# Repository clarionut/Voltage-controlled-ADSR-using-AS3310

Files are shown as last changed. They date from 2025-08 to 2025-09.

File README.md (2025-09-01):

# Voltage controlled ADSR using AS3310



This repository contains details of my modified version of the [Digisound 80-18 multifunction envelope generator]( http://www.digisound80.co.uk/digisound/modules/80-18.htm). I was particularly interested in its versatility with three operating modes
- normal (standard ADSR)
- automatic (gives a complete ADR cycle following a brief trigger input)
- damped (gives a piano-like envelope with initial attack and decay, but instead of a constant sustain while the gate is high the envelope continues to decay at a rate determined by the release setting, finally shutting off the envelope when the gate goes low)

Curiously, given that the 3310 chip is intrinsically voltage controlled, the Digisound 80-18 module only featured control of the envelope by potentiometers rather than allowing external CV control, although there are other designs (e.g. by [gerb-ster](https://github.com/gerb-ster/Curtis-VC-ADSR)) which do allow external control.

I'm absolutely delighted with this module and immediately built a second. I wouldn't want to be limited to a conventional ADSR having used this one.

## Issues
There is a known issue with the Digisound 80-18 module leading to repeated AD triggering with relatively weak gate inputs. The Digisound 80-18A documentation suggests using two gates from a CD40106 in series to condition the gate signal and [Eddy Bergman used a switch](https://www.eddybergman.com/2020/05/synthesizer-build-part-33-digisound-80.html) to break the loop responsible for multiple triggering. I chose to feed the gate input into an op-amp comparator so even rather low-level gates trigger the ADSR reliably.

Note that I have not encountered any of the odd behaviour in Automatic mode as described by Eddy Bergman, in my case this mode works exactly as described in the Digisound 80-18 documentation.

Running the circuit on a breadboard showed that with linear potentiometers much of the travel of the pot covered only very short time intervals, making the more useful longer times quite hard to adjust. This was easy to fix using fake C-taper pots (500k linear pot with a 100k resistor from the wiper to the +ve supply end of the pot).

## Additional features
I found that in Damped mode the final release was very rapid producing an audible click. Adding a 510R resistor between the AS3310 chip pin 13 and transistor TR2 (Digisound schematic) / Q2 (my schematic) gave a rapid release without clicking. In the end I added a 2k 'Release 2' pot to make this final release phase manually adjustable.

Coincidentally, at the time I was working on this circuit I was also fixing an issue with the envelope generator of the filter in my Formanta Polivoks. This has an autorepeat mode, enabled by setting the envelope to AD mode and the sustain level to zero. It uses an op-amp comparator to generate an internal trigger signal when the envelope voltage falls below a threshold of a few mV. I included this feature in this ADSR, providing an 'end of envelope' output to trigger other events in the synth, and included a LOOP option on the mode switch allowing the module to run continously (essentially as an 'ADR LFO') in Automatic mode with frequencies up to about 120Hz.

The decay CV input is normalled to the attack input and the release input is normalled to decay, allowing flexibility in external CV control.

There are out-of-range monitor LEDs on the four CV inputs to warn if the combined potentiometer & external CV levels exceed the maximum useful control voltage (no damage would result, it simply wouldn't be effective).

## Repository contents
The schematics folder contains the full schematic as a PDF document, the PCB layout (with the front ground plane removed for clarity) and a subfolder containing the kicad 7 project. The kicad schematic and PCB use some custom symbols and footprints so you may have to download my custom [kiCad libraries](https://github.com/clarionut/kiCad_libraries). Note that the PCB layout is intended to be processed by the 'round tracks' kicad plugin as shown in the PCB.pdf document. The kicad project files only include the unprocessed .kicad_pcb file. I've also included the Gerbers (in the Gerbers folder!) of the rounded tracks PCB for direct fabrication in case they're useful for anyone.

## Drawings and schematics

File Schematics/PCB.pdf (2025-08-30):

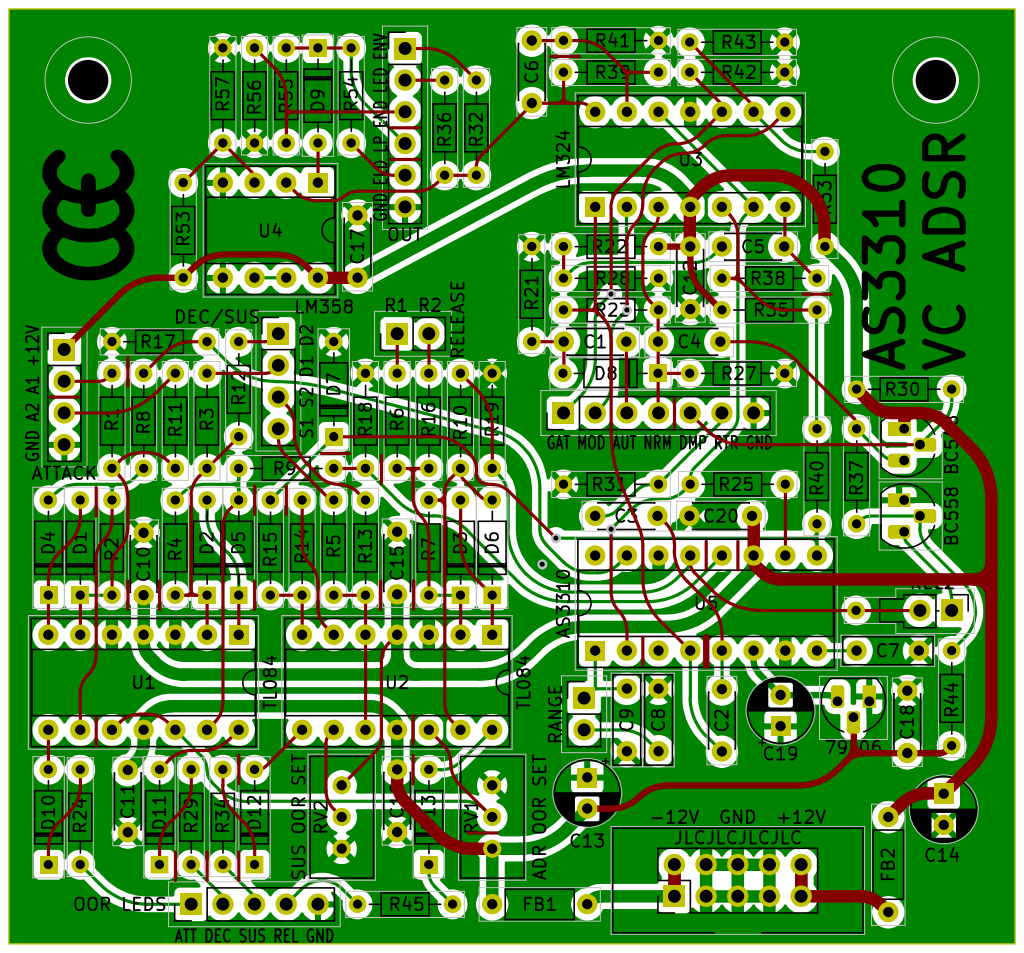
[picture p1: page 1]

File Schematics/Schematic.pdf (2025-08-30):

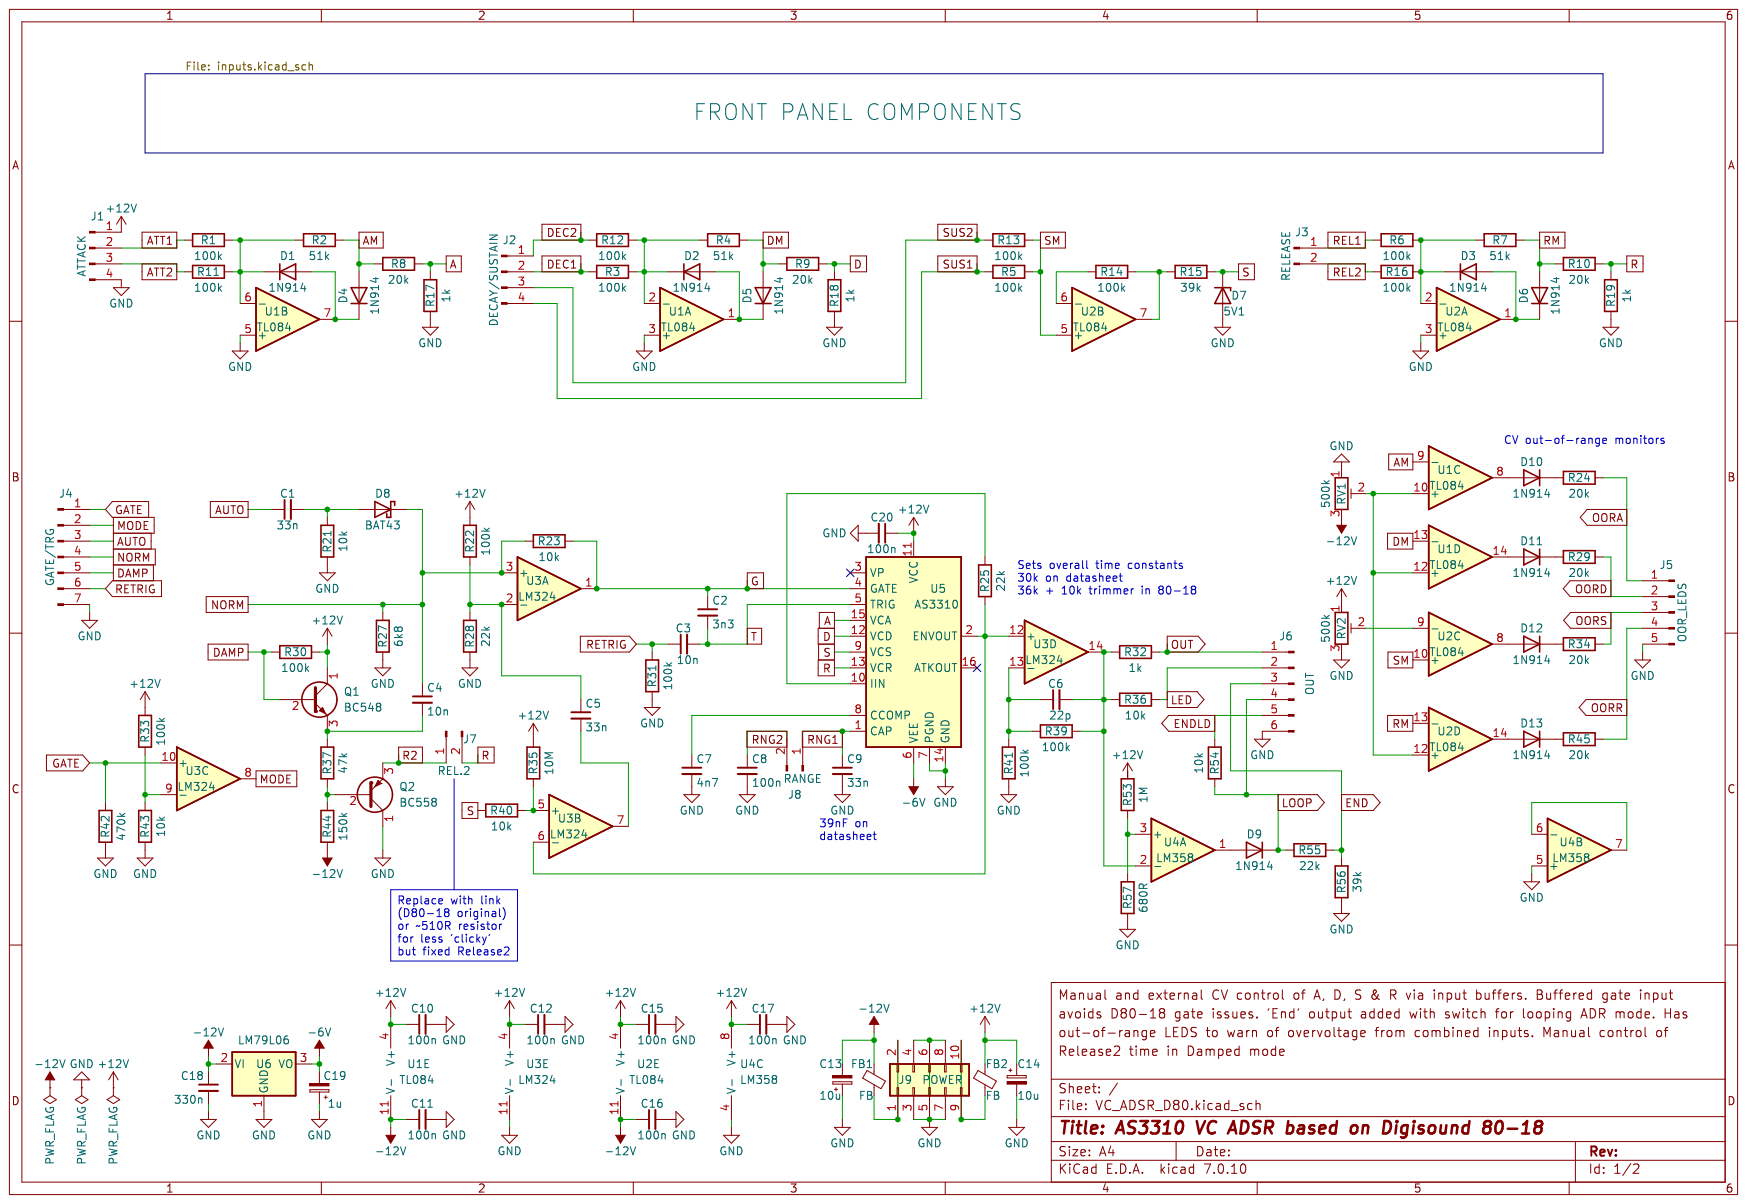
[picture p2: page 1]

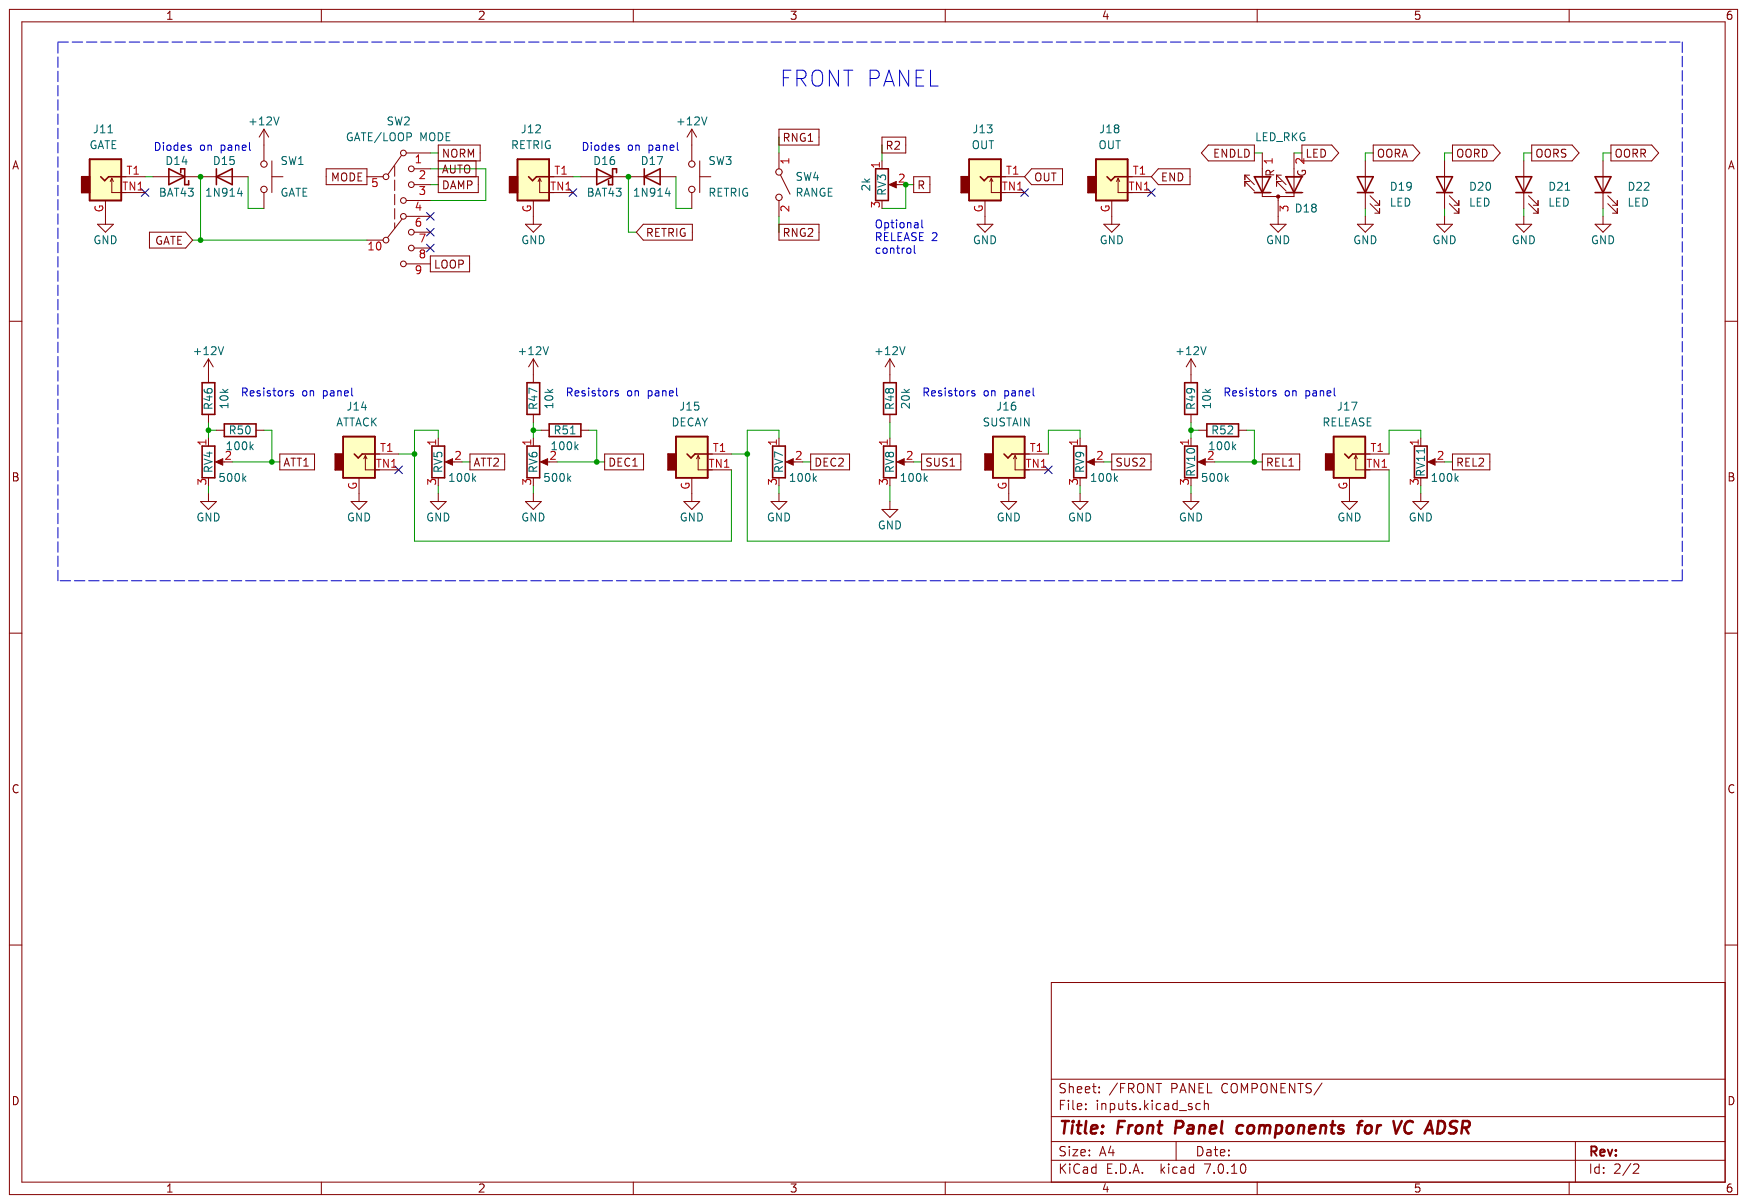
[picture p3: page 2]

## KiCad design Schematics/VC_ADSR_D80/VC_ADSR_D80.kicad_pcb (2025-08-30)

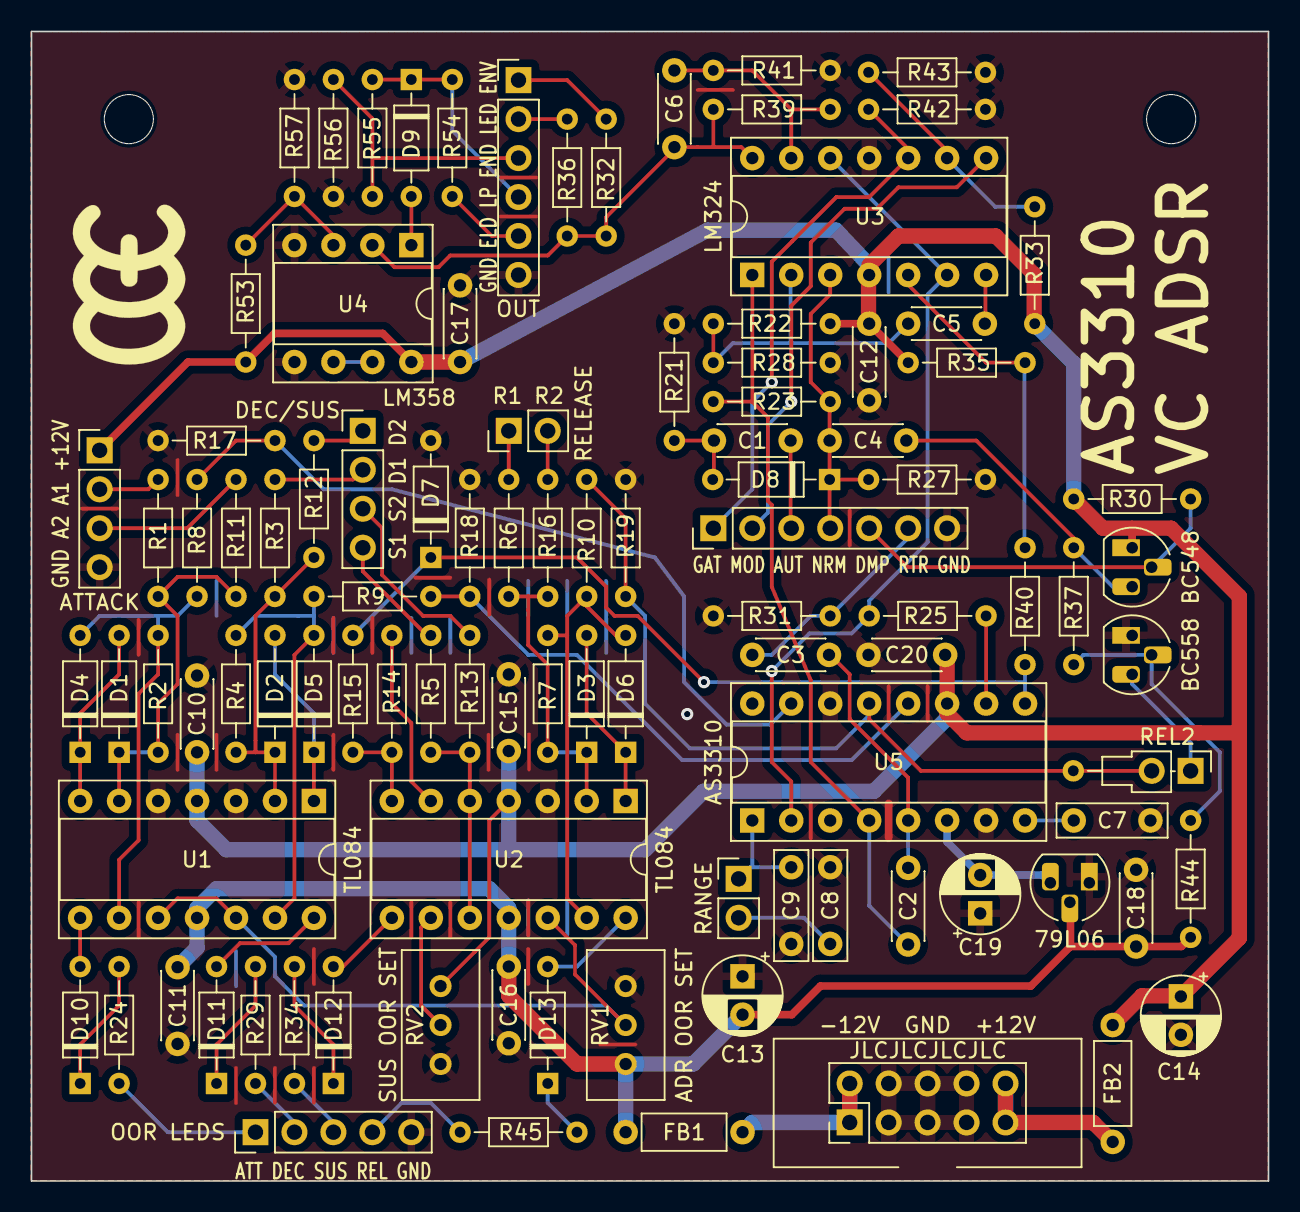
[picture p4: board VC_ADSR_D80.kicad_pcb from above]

Board: 2 copper layers, 80.6 x 74.9 mm, 101 parts (0 on the bottom side), 75 nets.

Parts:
C1, C5: 33n; C_Disc_D4.3mm_W1.9mm_P5.00mm
C2: 3n3; C_Disc_D4.3mm_W1.9mm_P5.00mm
C3, C4: 10n; C_Disc_D4.3mm_W1.9mm_P5.00mm
C6: 22p; C_Disc_D4.3mm_W1.9mm_P5.00mm
C7: 4n7; C_Rect_L7.0mm_W2.0mm_P5.00mm
C8: 100n; C_Rect_L7.0mm_W2.0mm_P5.00mm
C9: 33n; C_Rect_L7.0mm_W2.0mm_P5.00mm
C10, C11, C12, C15, C16, C17, C20: 100n; C_Disc_D4.3mm_W1.9mm_P5.00mm
C13, C14: 10u; CP_Radial_D5.0mm_P2.50mm
C18: 330n; C_Disc_D4.3mm_W1.9mm_P5.00mm
C19: 1u; CP_Radial_D5.0mm_P2.50mm
D1, D2, D3, D4, D5, D6, D9, D10, D11, D12, D13: 1N914; D_DO-35_SOD27_P7.62mm_Horizontal
D7: 5V1; D_DO-35_SOD27_P7.62mm_Horizontal
D8: BAT43; D_DO-35_SOD27_P7.62mm_Horizontal
FB1, FB2: FB; L_Axial_L5.3mm_D2.2mm_P7.62mm_Horizontal_Vishay_IM-1
J1: ATTACK; PinHeader_1x04_P2.54mm_Vertical
J2: DECAY/SUSTAIN; PinHeader_1x04_P2.54mm_Vertical
J3: RELEASE; PinHeader_1x02_P2.54mm_Vertical
J4: GATE/TRG; PinHeader_1x07_P2.54mm_Vertical
J5: OOR_LEDS; PinHeader_1x05_P2.54mm_Vertical
J6: OUT; PinHeader_1x06_P2.54mm_Vertical
J7: REL.2; Resistor_Header
J8: RANGE; PinHeader_1x02_P2.54mm_Vertical
J9: POWER; Power_2x05
Q1: BC548; TO-92_HandSolder
Q2: BC558; TO-92_HandSolder
R1, R3, R5, R6, R11, R12, R13, R14, R16, R22, R30, R31, R33, R39, R41: 100k; R_Axial_DIN0204_L3.6mm_D1.6mm_P7.62mm_Horizontal
R2, R4, R7: 51k; R_Axial_DIN0204_L3.6mm_D1.6mm_P7.62mm_Horizontal
R8, R9, R10, R24, R29, R34, R45: 20k; R_Axial_DIN0204_L3.6mm_D1.6mm_P7.62mm_Horizontal
R15, R56: 39k; R_Axial_DIN0204_L3.6mm_D1.6mm_P7.62mm_Horizontal
R17, R18, R19, R32: 1k; R_Axial_DIN0204_L3.6mm_D1.6mm_P7.62mm_Horizontal
R21, R23, R36, R40, R43, R54: 10k; R_Axial_DIN0204_L3.6mm_D1.6mm_P7.62mm_Horizontal
R25, R28, R55: 22k; R_Axial_DIN0204_L3.6mm_D1.6mm_P7.62mm_Horizontal
R27: 6k8; R_Axial_DIN0204_L3.6mm_D1.6mm_P7.62mm_Horizontal
R35: 10M; R_Axial_DIN0204_L3.6mm_D1.6mm_P7.62mm_Horizontal
R37: 47k; R_Axial_DIN0204_L3.6mm_D1.6mm_P7.62mm_Horizontal
R42: 470k; R_Axial_DIN0204_L3.6mm_D1.6mm_P7.62mm_Horizontal
R44: 150k; R_Axial_DIN0204_L3.6mm_D1.6mm_P7.62mm_Horizontal
R53: 1M; R_Axial_DIN0204_L3.6mm_D1.6mm_P7.62mm_Horizontal
R57: 680R; R_Axial_DIN0204_L3.6mm_D1.6mm_P7.62mm_Horizontal
RV1, RV2: 500k; Potentiometer_Bourns_3296W_Vertical
U1, U2: TL084; DIP-14_W7.62mm_Socket
U3: LM324; DIP-14_W7.62mm_Socket
U4: LM358; DIP-8_W7.62mm_Socket
U5: AS3310; DIP-16_W7.62mm_Socket
U6: LM79L06; TO-92_HandSolder

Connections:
+12V: C10.1, C12.1, C14.1, C15.1, C17.1, C20.1, FB2.1, J1.1, Q1.1 (C), R22.2, R30.1, R33.2, R35.2, R53.2, RV2.1, U1.4 (V+), U2.4 (V+), U3.4 (V+), U4.8 (V+), U5.11 (VCC)
-6V: C19.2, U5.6 (VEE), U6.3 (VO)
-12V: C11.1, C13.2, C16.1, C18.1, FB1.1, R44.1, RV1.3, U1.11 (V-), U2.11 (V-), U6.2 (VI)
A: R8.2, R17.2, U5.15 (VCA)
AM: D4.2 (A), R2.2, R8.1, U1.9 (-)
ATT1: J1.2, R1.1
ATT2: J1.3, R11.1
AUTO: C1.1, J4.3
D: R9.2, R18.2, U5.12 (VCD)
DAMP: J4.5, Q1.2 (B), R30.2
DEC1: J2.2, R3.1
DEC2: J2.1, R12.1
DM: D5.2 (A), R4.2, R9.1, U1.13 (-)
END: J6.3, R55.2, R56.2
ENDLD: J6.5, R54.2
G: C2.1, R23.2, U3.1, U5.4 (GATE)
GATE: J4.1, R42.2, U3.10 (+)
GND: C7.2, C8.2, C9.2, C10.2, C11.2, C12.2, C13.1, C14.2, C15.2, C16.2, C17.2, C18.2, C19.1, C20.2, D7.2 (A), J1.4, J4.7, J5.5, J6.6, J9.3, J9.4, J9.5, J9.6, J9.7, J9.8, Q2.1 (C), R17.1, R18.1, R19.1, R21.1, R27.1, R28.1, R31.1, R41.1, R42.1, R43.1, R56.1, R57.1, RV1.1, RV2.3, U1.3 (+), U1.5 (+), U2.3 (+), U3.11 (V-), U4.4 (V-), U4.5 (+), U5.7 (PGND), U5.14 (GND), U6.1 (GND)
LED: J6.2, R36.2
LOOP: D9.1 (K), J6.4, R54.1, R55.1
MODE: J4.2, U3.8
NORM: C4.1, D8.1 (K), J4.4, R23.1, R27.2, U3.3 (+)
unnamed: C5.2, U3.7
unnamed: D1.2 (A), D4.1 (K), U1.7
unnamed: D1.1 (K), R1.2, R2.1, R11.2, U1.6 (-)
unnamed: D2.2 (A), D5.1 (K), U1.1
unnamed: D2.1 (K), R3.2, R4.1, R12.2, U1.2 (-)
unnamed: D3.2 (A), D6.1 (K), U2.1
unnamed: D3.1 (K), R6.2, R7.1, R16.2, U2.2 (-)
unnamed: C1.2, D8.2 (A), R21.2
unnamed: D9.2 (A), U4.1
unnamed: D10.2 (A), U1.8
unnamed: D10.1 (K), R24.1
unnamed: D11.2 (A), U1.14
unnamed: D11.1 (K), R29.1
unnamed: D12.2 (A), U2.8
unnamed: D12.1 (K), R34.1
unnamed: D13.2 (A), U2.14
unnamed: D13.1 (K), R45.1
unnamed: FB1.2, J9.1, J9.2
unnamed: FB2.2, J9.9, J9.10
unnamed: C4.2, Q1.3 (E), R37.2
unnamed: Q2.2 (B), R37.1, R44.2
unnamed: R14.2, R15.1, U2.7
unnamed: RV1.2, U1.10 (+), U1.12 (+), U2.12 (+)
unnamed: R14.1, U2.6 (-)
unnamed: RV2.2, U2.9 (-)
unnamed: C5.1, R22.1, R28.2, U3.2 (-)
unnamed: R35.1, R40.2, U3.5 (+)
unnamed: R25.1, U3.6 (-), U3.12 (+), U5.2 (ENVOUT)
unnamed: R33.1, R43.2, U3.9 (-)
unnamed: C6.1, R39.1, R41.2, U3.13 (-)
unnamed: R53.1, R57.2, U4.3 (+)
unnamed: C6.2, R32.1, R36.1, R39.2, U3.14, U4.2 (-)
unnamed: U4.6 (-), U4.7
unnamed: C7.1, U5.8 (CCOMP)
unnamed: R25.2, U5.10 (IIN)
OORA: J5.1, R24.2
OORD: J5.2, R29.2
OORR: J5.4, R45.2
OORS: J5.3, R34.2
OUT: J6.1, R32.2
R: J7.2, R10.2, R19.2, U5.13 (VCR)
R2: J7.1, Q2.3 (E)
REL1: J3.1, R6.1
REL2: J3.2, R16.1
RETRIG: C3.1, J4.6, R31.2
RM: D6.2 (A), R7.2, R10.1, U2.13 (-)
RNG1: C9.1, J8.1, U5.1 (CAP)
RNG2: C8.1, J8.2
S: D7.1 (K), R15.2, R40.1, U5.9 (VCS)
SM: R5.2, R13.2, U2.5 (+), U2.10 (+)
SUS1: J2.4, R5.1
SUS2: J2.3, R13.1
T: C2.2, C3.2, U5.5 (TRIG)
